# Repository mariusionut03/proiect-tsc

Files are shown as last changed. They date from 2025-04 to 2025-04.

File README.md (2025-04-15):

# OpenBook e-book reader

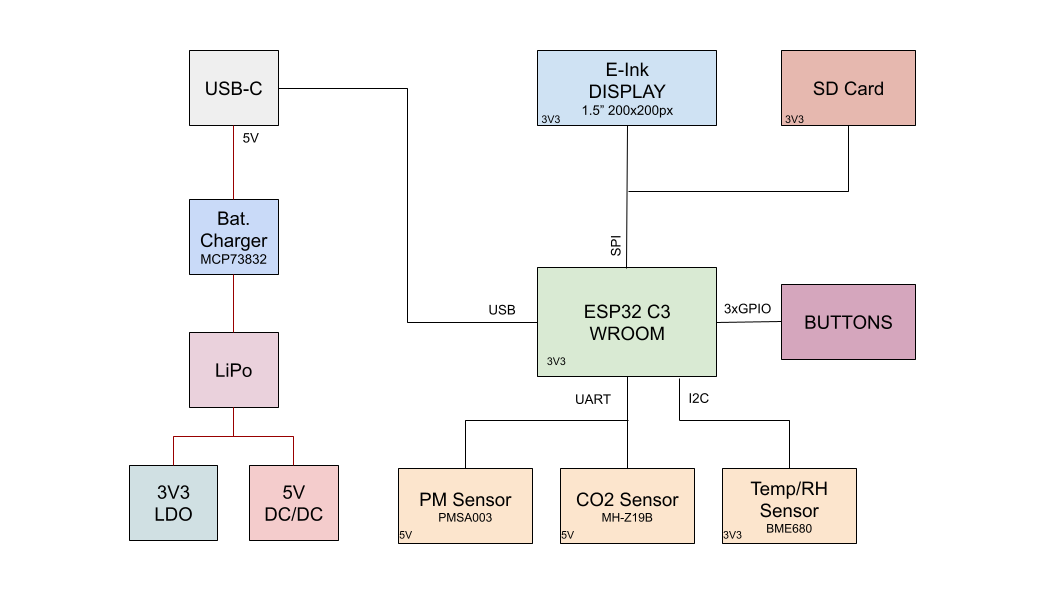
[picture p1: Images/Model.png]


## BOM - Bill of Materials

| Device Module | Amount | Datasheet | Shop |
| --- | --- | ---| ---|
| 112A-TAAR-R03_ATTEND | 1 | https://www.attend.com.tw/en/product.php?act=view&id=253 | https://www.digikey.com/en/products/detail/attend-technology/112A-TAAR-R03/17633923 |
| BD5229G-TR | 1 | https://www.digikey.ph/en/products/detail/rohm-semiconductor/BD5229G-TR/658502 | https://www.digikey.ph/en/products/detail/rohm-semiconductor/BD5229G-TR/658502 |
| BUTTON_COSYOMV1 | 3 | https://components101.com/switches/push-button | https://uk.farnell.com/wurth-elektronik/430182043816/switch-160gf-6x6mm-smd-4-3mm-act/dp/2065105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 |
| CPH3225A | 1 | https://www.digikey.com/en/products/detail/seiko-instruments/CPH3225A/8692444 | https://www.digikey.com/en/products/detail/seiko-instruments/CPH3225A/8692444 |
| DS3231SN | 1 | https://www.digikey.com/en/products/detail/analog-devices-inc-maxim-integrated/DS3231SN/1197576 | https://www.digikey.com/en/products/detail/analog-devices-inc-maxim-integrated/DS3231SN/1197576 |
| BME680 | 1 | https://www.sparkfun.com/sparkfun-environmental-sensor-breakout-bme680-qwiic.html | https://www.sparkfun.com/sparkfun-environmental-sensor-breakout-bme680-qwiic.html |
| MCP73831 | 1 | https://www.microchip.com/en-us/product/mcp73831 | https://www.microchipdirect.com/product/MCP73831T-2ADI/OT |
| C6-WROOM-1-N8 | 1 | https://www.espressif.com/sites/default/files/documentation/esp32-c6-wroom-1_wroom-1u_datasheet_en.pdf | https://www.adafruit.com/product/5671 |
| FH34SRJ-24S-0.5SH_99_ | 1 | https://www.hirose.com/product/p/CL0580-1255-6-99 | https://www.hirose.com/product/p/CL0580-1255-6-99 |
| MAX17048G+T10 | 1 | https://eu.mouser.com/ProductDetail/Analog-Devices-Maxim-Integrated/MAX17048G+T10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 | https://eu.mouser.com/ProductDetail/Analog-Devices-Maxim-Integrated/MAX17048G+T10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 |
| MBR0530 | 3 | https://www.digikey.com/en/products/detail/onsemi/MBR0530/1048783 | https://www.digikey.com/en/products/detail/onsemi/MBR0530/1048783 |
| PGB1010603MR | 6 | https://www.digikey.com/en/products/detail/littelfuse-inc/PGB1010603MR/715755 | https://www.digikey.com/en/products/detail/littelfuse-inc/PGB1010603MR/715755 |
| SAMACSYS_PARTS_USB4110-GF-A | 1 | https://www.digikey.ro/en/products/detail/gct/USB4110-GF-A/10384547 | https://www.digikey.ro/en/products/detail/gct/USB4110-GF-A/10384547 |
| SI1308EDL-T1-GE3 | 1 | https://www.digikey.com/en/products/detail/vishay-siliconix/SI1308EDL-T1-GE3/4876435 | https://www.digikey.com/en/products/detail/vishay-siliconix/SI1308EDL-T1-GE3/4876435 |
| SJ | 1 | https://www.digikey.com/en/products/detail/cui-devices/SJ1-3514N/738685 | https://www.digikey.com/en/products/detail/cui-devices/SJ1-3514N/738685 |
| USBLC6-2SC6Y | 1 | https://www.digikey.com/en/products/detail/stmicroelectronics/USBLC6-2SC6Y/2819177 | https://www.digikey.com/en/products/detail/stmicroelectronics/USBLC6-2SC6Y/2819177 |
| W25Q512JVEIQ | 1 | https://www.digikey.com/en/products/detail/winbond-electronics/W25Q512JVEIQ/10244706 | https://www.digikey.com/en/products/detail/winbond-electronics/W25Q512JVEIQ/10244706 |
| XC6220A331MR-G | 1 | https://www.digikey.com/en/products/detail/torex-semiconductor-ltd/XC6220B331MR-G/2138177 | https://www.digikey.com/en/products/detail/torex-semiconductor-ltd/XC6220B331MR-G/2138177 |
| SD0805S020S1R0 | 2 | https://www.digikey.com/en/products/detail/kyocera-avx/SD0805S020S1R0/3749517 | https://www.digikey.com/en/products/detail/kyocera-avx/SD0805S020S1R0/3749517 |
| LTSPICE_C 100nF | 8 | https://www.digikey.com/en/products/detail/nextgen-components/0402B104K500HI/22601924 | https://www.digikey.com/en/products/detail/nextgen-components/0402B104K500HI/22601924 |
| LTSPICE_C 10nF | 1 | https://www.amazon.com/ALLECIN-Electrolytic-Capacitor-0-2x0-43in-Capacitors/dp/B0CMQC587X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 | https://www.amazon.com/ALLECIN-Electrolytic-Capacitor-0-2x0-43in-Capacitors/dp/B0CMQC587X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 |
| LTSPICE_C 4.7uF | 6 | https://www.amazon.com/ALLECIN-Electrolytic-Capacitor-0-2x0-43in-Capacitors/dp/B0CMQC587X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 | https://www.amazon.com/ALLECIN-Electrolytic-Capacitor-0-2x0-43in-Capacitors/dp/B0CMQC587X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 |
| LTSPICE_C 1uF | 10 | https://www.amazon.com/ALLECIN-Electrolytic-Capacitor-0-2x0-43in-Capacitors/dp/B0CMQC587X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 | https://www.amazon.com/ALLECIN-Electrolytic-Capacitor-0-2x0-43in-Capacitors/dp/B0CMQC587X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 |
| LTSPICE_C 0.1uF | 1 | https://www.digikey.com/en/products/detail/samsung-electro-mechanics/CL10E104KC8VPNC/20498486 | https://www.digikey.com/en/products/detail/samsung-electro-mechanics/CL10E104KC8VPNC/20498486 |
| ADAFRUIT_LED | 1 | https://www.adafruit.com/product/4684 | https://www.adafruit.com/product/4684 |
| ESP32_VARISTOR | 1 | https://uk.rs-online.com/web/p/varistors/9012743 | https://uk.rs-online.com/web/p/varistors/9012743 |
| CT3528 (RCL_CPOL-EU) 100uF | 1 | https://www.datasheetarchive.com/?q=ct3528 |  |
| DMG2305UX-7 20V/4.2A/52mO/1.4W | 2 | https://www.digikey.com/en/products/detail/diodes-incorporated/DMG2305UX-7/4340667 | https://www.digikey.com/en/products/detail/diodes-incorporated/DMG2305UX-7/4340667 |
| IND-4828-WE-TPC-WRE | 1 | https://www.axel-gl.com/en/asone/d/64-0172-48/ | https://www.axel-gl.com/en/asone/d/64-0172-48/ |
| JS-1MM(QWIIC_CONNECTOR) | 1 | https://www.sparkfun.com/qwiic-jst-connector-smd-4-pin-horizontal.html | https://www.sparkfun.com/qwiic-jst-connector-smd-4-pin-horizontal.html |
| LTSPICE_R 5k1 | 2 |  | https://www.amazon.com/BOJACK-Values-Resistor-Resistors-Assortment/dp/B08FD1XVL6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 |
| LTSPICE_R 100k | 1 |  | https://www.amazon.com/BOJACK-Values-Resistor-Resistors-Assortment/dp/B08FD1XVL6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 |
| LTSPICE_R 2.2 | 1 |  | https://www.amazon.com/BOJACK-Values-Resistor-Resistors-Assortment/dp/B08FD1XVL6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 |
| LTSPICE_R 10k | 16 |  | https://www.amazon.com/BOJACK-Values-Resistor-Resistors-Assortment/dp/B08FD1XVL6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 |
| LTSPICE_R 0.47 | 1 |  | https://www.amazon.com/BOJACK-Values-Resistor-Resistors-Assortment/dp/B08FD1XVL6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 |
| LTSPICE_R 2k | 1 |  | https://www.amazon.com/BOJACK-Values-Resistor-Resistors-Assortment/dp/B08FD1XVL6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 |
| LTSPICE_R 200 | 1 |  | https://www.amazon.com/BOJACK-Values-Resistor-Resistors-Assortment/dp/B08FD1XVL6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 |
| LTSPICE_R 15 | 1 |  | https://www.amazon.com/BOJACK-Values-Resistor-Resistors-Assortment/dp/B08FD1XVL6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 |
| Test Pad TP20R | 17 | https://us.misumi-ec.com/vona2/detail/221005496391/?HissuCode=TP20R-24 | https://us.misumi-ec.com/vona2/detail/221005496391/?HissuCode=TP20R-24 |

## ESP32-C6

- EN - RESET (Activare sau dezactivare device)
- IO0 - INT_RTC (Pin pentru intrerupere ale ceasului RTC sau Real Time Clock)
- IO1 - 32KHZ (Ofera o frecventa de 32 kHz, utilizata pentru sincronizare.)
- IO2 - MISO (Master In Slave Out, comunicare SPI pentru primire date de la periferice)
- IO3 - EPD_BUSY (Indica starea ecranului: ocupat sau liber)
- IO4 - SS_SD (Activeaza cardul SD, Slave Select)
- IO5 - EPD_DC (Control pentru date si comenzi ecran)
- IO6 - SCK (Serial Clock)
- IO7 - MOSI (Master Out Slave In, comunicare SPI pentru trimitere date la periferice)
- IO8 - GPIO8
- IO9 - IO/BOOT (Schimbare state dispozitiv)
- IO10 - EPD_CS (Select display)
- IO11 - FLASH_CS (Select memoria Flash)
- IO12 - USB_D- (comunicare USB)
- IO13 - USB_D+ (comunicare USB)
- IO15 - IO/CHANGE (navigare)
- IO16 - TX (Transmitere date)
- IO17 - RX (Receptie date)
- IO18 - RTC_RST (Reset RTC)
- IO19 - I2C_PW (Linia de alimentare pentru periferice I2C)
- IO20 - EPD_3V3_C (Alimentare)
- IO21 - SDA (I2C Data)
- IO22 - SCL (I2C Clock)
- IO23 - EPD_RST (Reset display)
- GND - Connected to ground 

## Randari

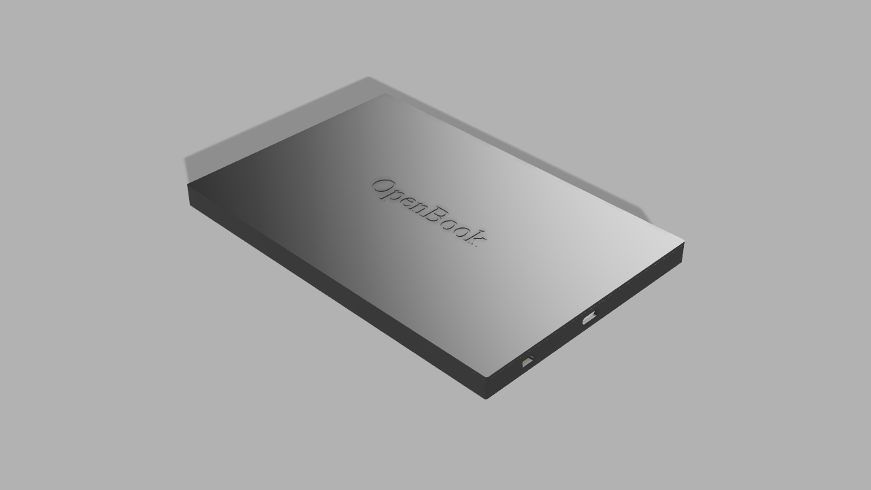
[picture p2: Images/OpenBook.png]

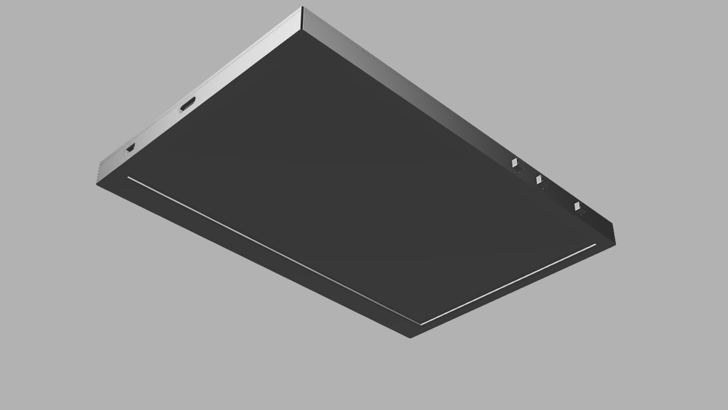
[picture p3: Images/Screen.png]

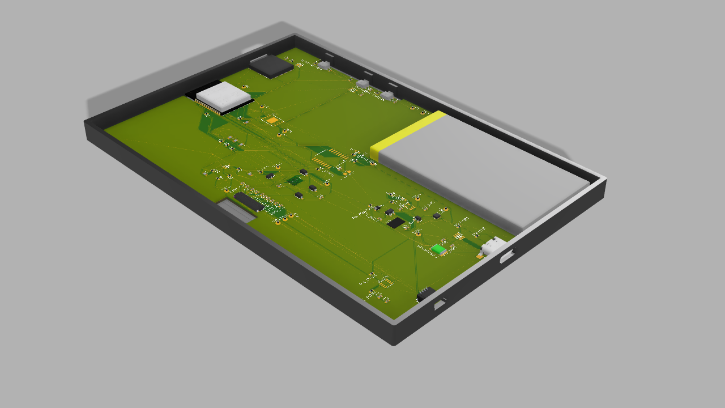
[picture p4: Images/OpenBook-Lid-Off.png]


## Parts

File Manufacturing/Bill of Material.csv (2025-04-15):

Qty | Value | Device | Package | Parts | Description | ARROW_PART_NUMBER | ARROW_PRICE-STOCK | AVAILABILITY | BOOT_BUTTON | CENTROID_NOT_SPECIFIED | CHANGE_BUTTON | CHECK_PRICES | COPYRIGHT | DATASHEET | DESCRIPTION | DIGIKEY_DESCRIPTION | DIGIKEY_PART_NUMBER | HEIGHT | LEAD_FREE | MANUFACTURER_NAME | MANUFACTURER_PART_NUMBER | MF | MFR_NAME | MOUSER_PART_NUMBER | MOUSER_PRICE-STOCK | MOUSER_TESTING_PART_NUMBER | MOUSER_TESTING_PRICE-STOCK | MP | MPN | PACKAGE | POPULARITY | PREFIX | PRICE | PROD_ID | PURCHASE-URL | RESET_BUTTON | ROHS | SNAPEDA_LINK | SPICEPREFIX | TEMPERATURE_RANGE_HIGH | TEMPERATURE_RANGE_LOW | VALUE
1 |  | ADAFRUIT_LEDCHIP-LED0603 | ADAFRUIT_CHIP-LED0603 | CHG_LED | LED
1 |  | SJ | SJ | SJ1 | SMD solder JUMPER |  |  |  |  |  |  |  |  |  |  |  |  |  |  |  |  |  |  |  |  |  |  |  |  |  | 3
1 | 0.1uF/50V | ESP32_WROVER_EAGLE-LTSPICE_C | ESP32_WROVER_EAGLE-LTSPICE_C0402 | EPD_C5 | CAPACITOR, European symbol
1 | 0.47 | ESP32_WROVER_EAGLE-LTSPICE_R | ESP32_WROVER_EAGLE-LTSPICE_R0402 | R3 | RESISTOR, European symbol
1 | 100K | ESP32_WROVER_EAGLE-LTSPICE_R | ESP32_WROVER_EAGLE-LTSPICE_R0402 | R1_PWRUSB | RESISTOR, European symbol
8 | 100nF | ESP32_WROVER_EAGLE-LTSPICE_C | ESP32_WROVER_EAGLE-LTSPICE_C0402 | C1, C2, C4_USB, C6, C8, C9, C10, C_DELAY | CAPACITOR, European symbol
1 | 100uF TANT | RCL_CPOL-EUCT3528 | RCL_CT3528 | C3 | POLARIZED CAPACITOR, European symbol |  |  |  |  |  |  |  |  |  |  |  |  |  |  |  |  |  |  |  |  |  |  |  |  |  | 0 |  |  |  |  |  |  |  | C
16 | 10K | ESP32_WROVER_EAGLE-LTSPICE_R | ESP32_WROVER_EAGLE-LTSPICE_R0402 | R1, R1_PINH, R1_PINH1, R2_PINH, R2_PINH1, R4, R5, R6, R7, R8, R9, R10, R_BOOT, R_CHARGE, R_CL1, R_RESET | RESISTOR, European symbol
1 | 10uF | ESP32_WROVER_EAGLE-LTSPICE_C | ESP32_WROVER_EAGLE-LTSPICE_C0402 | C7 | CAPACITOR, European symbol
1 | 112A-TAAR-R03_ATTEND | 112A-TAAR-R03_ATTEND | 112ATAARR03ATTEND | J4 | Micro SD Card Socket, Push-Push Type, Top Mount, SMT, H=1.83mm, 10u |  |  |  |  |  |  |  |  |  | Micro SD Card Socket | Push-Push Type | Top Mount | SMT | H=1.83mm | 10u |  |  | 1.9mm |  | ATTEND | 112A-TAAR-R03 ATTEND
1 | 15 | ESP32_WROVER_EAGLE-LTSPICE_R | ESP32_WROVER_EAGLE-LTSPICE_R0402 | R_CAPACITOR | RESISTOR, European symbol
1 | 1uF | ESP32_WROVER_EAGLE-LTSPICE_C | ESP32_WROVER_EAGLE-LTSPICE_C0402 | C5 | CAPACITOR, European symbol
9 | 1uF/50V | ESP32_WROVER_EAGLE-LTSPICE_C | ESP32_WROVER_EAGLE-LTSPICE_C0402 | EPD_C1, EPD_C2, EPD_C6, EPD_C7, EPD_C8, EPD_C9, EPD_C10, EPD_C11, EPD_C12 | CAPACITOR, European symbol
1 | 2.2 | ESP32_WROVER_EAGLE-LTSPICE_R | ESP32_WROVER_EAGLE-LTSPICE_R0402 | R2 | RESISTOR, European symbol
1 | 200 | ESP32_WROVER_EAGLE-LTSPICE_R | ESP32_WROVER_EAGLE-LTSPICE_R0402 | R1_BAT | RESISTOR, European symbol
2 | 20V/4.2A/52mO/1.4W | ESP32_WROVER_SPARKFUN-DISCRETESEMI_MOSFET_PCH-DMG2305UX-7 | ESP32_WROVER_SPARKFUN-DISCRETESEMI_SOT23-3 | Q1, Q2 | P-channel MOSFETs |  |  |  |  |  |  |  |  |  |  |  |  |  |  |  |  |  |  |  |  |  |  |  |  |  |  |  |  | TRAN-14388 |  |  |  |  |  |  |  | 20V/4.2A/52mO/1.4W
1 | 2K | ESP32_WROVER_EAGLE-LTSPICE_R | ESP32_WROVER_EAGLE-LTSPICE_R0402 | R2_BAT | RESISTOR, European symbol
5 | 4.7uF | ESP32_WROVER_EAGLE-LTSPICE_C | ESP32_WROVER_EAGLE-LTSPICE_C0402 | C1_BAT, C1_BAT1, C1_BAT2, C2_BAT, C5_USB | CAPACITOR, European symbol
1 | 4.7uF/25V | ESP32_WROVER_EAGLE-LTSPICE_C | ESP32_WROVER_EAGLE-LTSPICE_C0402 | C4 | CAPACITOR, European symbol
2 | 5k1 | ESP32_WROVER_EAGLE-LTSPICE_R | ESP32_WROVER_EAGLE-LTSPICE_R0402 | R2-USB, R2-USB1 | RESISTOR, European symbol
1 | 68uH | 744043680IND_4828-WE-TPC_WRE | IND_4828-WE-TPC_WRE | L1 |  |  |  |  |  |  |  |  | Copyright (C) 2024 Ultra Librarian. All rights reserved. |  |  |  |  |  |  |  | 744043680 |  | Wurth Electronics
1 | BD5229G-TR | BD5229G-TR | SOT95P280X125-5N | IC1 | Voltage Detector with Adjustable Delay Time: CMOS processes are utilized to develop high precision, low current consumption CMOS reset ICs that allow arbitrary setting of the delay time. The extensive lineup includes both Nch Open Drain and CMOS output types in a wide range of detection voltages (from 2.3V to 6.0V, in 0.1V steps), enabling selection of the ideal solution based on customer requirements. In addition, the entire series is of course both lead-free and RoHS-compliant. |  |  |  |  |  |  |  |  |  | Voltage Detector with Adjustable Delay Time: CMOS processes are utilized to develop high precision | low current consumption CMOS reset ICs that allow arbitrary setting of the delay time. The extensive lineup includes both Nch Open Drain and CMOS output types in a wide range of detection voltages (from 2.3V to 6.0V | in 0.1V steps) | enabling selection of the ideal solution based on customer requirements. In addition | the entire series is of course both lead-free and RoHS-compliant. |  |  | 1.25mm |  | ROHM Semiconductor | BD5229G-TR |  |  | 755-BD5229G-TR | https://www.mouser.co.uk/ProductDetail/ROHM-Semiconductor/BD5229G-TR?qs=4kLU8WoGk0vvnhrrYwdszw%3D%3D
3 | BUTTON_CUSYOMV1BUTTONMODEL | BUTTON_CUSYOMV1BUTTONMODEL | MYBUTTON | CHANGE_BUTTON, RESET_BUTTON, U$2
1 | CPH3225A | CPH3225A | CAPCP3225X100N | C10_SUPERCAP | Cap 0.011F 3.3V 1210 Flat Check availability |  |  | Not in stock |  |  |  | https://www.snapeda.com/parts/CPH3225A/Seiko+Instruments/view-part/?ref=eda |  |  | 11 mF (EDLC) Supercapacitor 3.3 V 1210 (3225 Metric) - - |  |  |  |  |  |  | Seiko Instruments |  |  |  |  |  | CPH3225A |  | 1210 Seiko |  |  | None |  | https://www.snapeda.com/api/url_track_click_mouser/?unipart_id=562593&manufacturer=Seiko Instruments&part_name=CPH3225A&search_term=None |  |  | https://www.snapeda.com/parts/CPH3225A/Seiko+Instruments/view-part/?ref=snap
1 | DS3231SN# | DS3231SN# | SOIC127P1032X265-16N | U3 | Real Time Clock Serial 16-Pin SOIC W T/R Check availability |  |  | In Stock |  |  |  | https://www.snapeda.com/parts/DS3231SN%23/Analog+Devices/view-part/?ref=eda |  |  | Extremely Accurate I²C-Integrated RTC/TCXO/Crystal |  |  |  |  |  |  | Analog Devices |  |  |  |  |  | DS3231SN# |  | SOIC-16 Maxim |  |  | None |  | https://www.snapeda.com/api/url_track_click_mouser/?unipart_id=99048&manufacturer=Analog Devices&part_name=DS3231SN#&search_term=None |  |  | https://www.snapeda.com/parts/DS3231SN%23/Analog+Devices/view-part/?ref=snap
1 | ESP32-C6-WROOM-1-N8 | ESP32-C6-WROOM-1-N8 | XCVR_ESP32-C6-WROOM-1-N8 | U2 | Check availability |  |  | In Stock |  |  |  | https://www.snapeda.com/parts/ESP32-C6-WROOM-1-N8/Espressif+Systems/view-part/?ref=eda |  |  | Multiprotocol Modules ESP32-C6 module | Wi-Fi 6 in 2.4 GHz band | Bluetooth 5 | Zigbee 3.0 and Thread. ESP34-WROOM Compatible - ENGINEERING SAMPLE |  |  |  |  |  |  | Espressif Systems |  |  |  |  |  | ESP32-C6-WROOM-1-N8 |  | None |  |  | None |  |  |  |  | https://www.snapeda.com/parts/ESP32-C6-WROOM-1-N8/Espressif+Systems/view-part/?ref=snap
1 | ESP32C6_VARISTORCN1812 | ESP32C6_VARISTORCN1812 | ESP32C6_VARISTOR_CT/CN1812 | PFMF.050.1 | VARISTOR |  |  |  |  |  |  |  |  |  |  |  |  |  |  |  |  |  |  |  |  |  |  |  |  |  | 0
2 | ESP32_WROVER_AVX---SD0805S020S1R0_AVX_SD0805S020S1R0_0_0AVX_SD0805S020S1R0_0_0 | ESP32_WROVER_AVX---SD0805S020S1R0_AVX_SD0805S020S1R0_0_0AVX_SD0805S020S1R0_0_0 | ESP32_WROVER_AVX---SD0805S020S1R0_AVX_SD0805S020S1R0_0 | D2, D7 | Schottky Barrier Rectifier Diode |  |  |  |  | No |  |  |  | http://datasheets.avx.com/schottky.pdf |  | DIODE SCHOTTKY 20V 1A 0805 | 478-7800-1-ND |  | yes |  |  | AVX |  | 581-SD0805S020S1R0 |  |  |  |  |  | 0805 (2012 metric) |  | D |  |  |  |  | yes |  |  | +125°C | -55°C
1 | ESP32_WROVER_BME680_BME680 | ESP32_WROVER_BME680_BME680 | ESP32_WROVER_BME680_PSON80P300X300X100-8N | SENSOR2 | Integrated Environmental Unit |  |  | Unavailable |  |  |  |  |  |  | Integrated Environmental Unit |  |  |  |  |  |  | Bosch Sensortec |  |  |  |  |  | BME680 |  | LGA-8 Bosch Tools |  |  | None
1 | ESP32_WROVER_SPARKFUN-IC-POWER_MCP73831 | ESP32_WROVER_SPARKFUN-IC-POWER_MCP73831 | ESP32_WROVER_SPARKFUN-IC-POWER_SOT23-5 | MCP73831 | MCP73831T Li-Ion, Li-Pol Controller |  |  |  |  |  |  |  |  |  |  |  |  |  |  |  |  |  |  |  |  |  |  |  |  |  |  |  |  | IC-09995
1 | FH34SRJ-24S-0.5SH_99_ | FH34SRJ-24S-0.5SH_99_ | FH34SRJ24S05SH99 | J1 | (0.50mm) Surface Mount, Right Angle |  |  |  |  |  |  |  |  |  | 24 Position FFC | FPC Connector Contacts | (0.50mm) Surface Mount | Right Angle |  |  | 1.1mm |  | Hirose | FH34SRJ-24S-0.5SH(99) |  |  | 798-FH34SRJ24S05SH99 | https://www.mouser.co.uk/ProductDetail/Hirose-Connector/FH34SRJ-24S-0.5SH99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
1 | MAX17048G+T10 | MAX17048G+T10 | SON50P200X200X80-9N | U4 | Check availability |  |  | In Stock |  |  |  | https://www.snapeda.com/parts/MAX17048G+T10/Analog+Devices/view-part/?ref=eda |  |  | 3µA 1-Cell/2-Cell Fuel Gauge with ModelGauge |  |  |  |  |  |  | Analog Devices |  |  |  |  |  | MAX17048G+T10 |  | TDFN-8 Maxim |  |  | None |  | https://www.snapeda.com/api/url_track_click_mouser/?unipart_id=329239&manufacturer=Analog Devices&part_name=MAX17048G+T10&search_term=None |  |  | https://www.snapeda.com/parts/MAX17048G+T10/Analog+Devices/view-part/?ref=snap
3 | MBR0530COSTUM | MBR0530COSTUM | SOD3716X135N | D3, D4, D5 | ON SEMICONDUCTOR - MBR0530 - DIODE, SCHOTTKY, 0.5A, 30V, SOD-123
6 | PGB1010603MRCOSTUM | PGB1010603MRCOSTUM | DIOC1608X36N | D6, D8, D9, D10, D11, D12 | Check availability
1 | QWIIC_RIGHT_ANGLE | QWIIC_CONNECTORJS-1MM | JST04_1MM_RA | J3 | SparkFun I2C Standard Qwiic Connector |  |  |  |  |  |  |  |  |  |  |  |  |  |  |  |  |  |  |  |  |  |  |  |  |  |  |  |  | CONN-13694 |  |  |  |  |  |  |  | QWIIC_RIGHT_ANGLE
1 | SAMACSYS_PARTS_USB4110-GF-A | SAMACSYS_PARTS_USB4110-GF-A | SAMACSYS_PARTS_USB4110GFA | J2 | CONN USB 2.0 TYPE-C R/A SMT |  |  |  |  |  |  |  |  |  | CONN USB 2.0 TYPE-C R/A SMT |  |  | 3.26mm |  | GCT (GLOBAL CONNECTOR TECHNOLOGY) | USB4110-GF-A |  |  | 640-USB4110-GF-A | https://www.mouser.co.uk/ProductDetail/GCT/USB4110-GF-A?qs=KUoIvG%2F9IlYiZvIXQjyJeA%3D%3D
1 | SI1308EDL-T1-GE3 | SI1308EDL-T1-GE3 | SOT65P210X110-3N | Q3 | MOSFET N-Ch 30V 1.5A TrenchFET SC70 Vishay Si1308EDL-T1-GE3 N-channel MOSFET Transistor, 1.5 A, 30 V, 3-Pin SC-70 |  |  | In Stock |  |  |  | https://www.snapeda.com/parts/SI1308EDL-T1-GE3/Vishay+Siliconix/view-part/?ref=eda |  |  | Si1308EDL-T1-GE3 N-channel MOSFET Transistor | 1.5 A | 30 V | 3-Pin SC-70 | Siliconix / Vishay SI1308EDL-T1-GE3 |  |  |  |  |  |  | Vishay Siliconix |  |  |  |  |  | SI1308EDL-T1-GE3 |  | SOT-323 Vishay Semiconductor |  |  | None |  | https://www.snapeda.com/api/url_track_click_mouser/?unipart_id=274603&manufacturer=Vishay Siliconix&part_name=SI1308EDL-T1-GE3&search_term=None |  |  | https://www.snapeda.com/parts/SI1308EDL-T1-GE3/Vishay+Siliconix/view-part/?ref=snap
17 | TP | TP | TP20R | TP1, TP2, TP3, TP4, TP5, TP6, TP7, TP8, TP9, TP10, TP11, TP12, TP13, TP14, TP15, TP16, TP17 | Test pad
1 | USBLC6-2SC6Y | USBLC6-2SC6Y | SOT95P280X145-6N | D1 | Low Cap. ESD Protection Auto SOT-23-6 STMicroelectronics USBLC6-2SC6Y, Dual Uni-Directional TVS Diode Array, 6-Pin SOT-23 |  |  | In Stock |  |  |  | https://www.snapeda.com/parts/USBLC6-2SC6Y/STMicroelectronics/view-part/?ref=eda |  |  | 17V Clamp 5A (8/20µs) Ipp Tvs Diode Surface Mount SOT-23-6 |  |  |  |  |  |  | STMicroelectronics |  |  |  |  |  | USBLC6-2SC6Y |  | SOT-23-6 STMicroelectronics |  |  | None |  |  |  |  | https://www.snapeda.com/parts/USBLC6-2SC6Y/STMicroelectronics/view-part/?ref=snap
1 | W25Q512JVEIQ | W25Q512JVEIQ | SON127P600X800X80-9N | U1 | Check availability |  |  | In Stock |  |  |  | https://www.snapeda.com/parts/W25Q512JVEIQ/Winbond+Electronics/view-part/?ref=eda |  |  | FLASH - NOR Memory IC 512Mb (64M x 8) SPI - Quad I/O 133 MHz 8-WSON (8x6) |  |  |  |  |  |  | Winbond Electronics |  |  |  |  |  | W25Q512JVEIQ |  | Package |  |  | None |  |  |  |  | https://www.snapeda.com/parts/W25Q512JVEIQ/Winbond+Electronics/view-part/?ref=snap
1 | XC6220A331MR-G | XC6220A331MR-G | SOT95P280X120-5N | IC4 | LDO Voltage Regulators |  |  |  |  |  |  |  |  |  | LDO Voltage Regulators |  |  | 1.2mm |  | Torex | XC6220A331MR-G |  |  | 865-XC6220A331MR-G | https://www.mouser.co.uk/ProductDetail/Torex-Semiconductor/XC6220A331MR-G?qs=AsjdqWjXhJ8ZSWznL1J0gg%3D%3D

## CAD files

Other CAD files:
Mechanical/OpenBook.f3z

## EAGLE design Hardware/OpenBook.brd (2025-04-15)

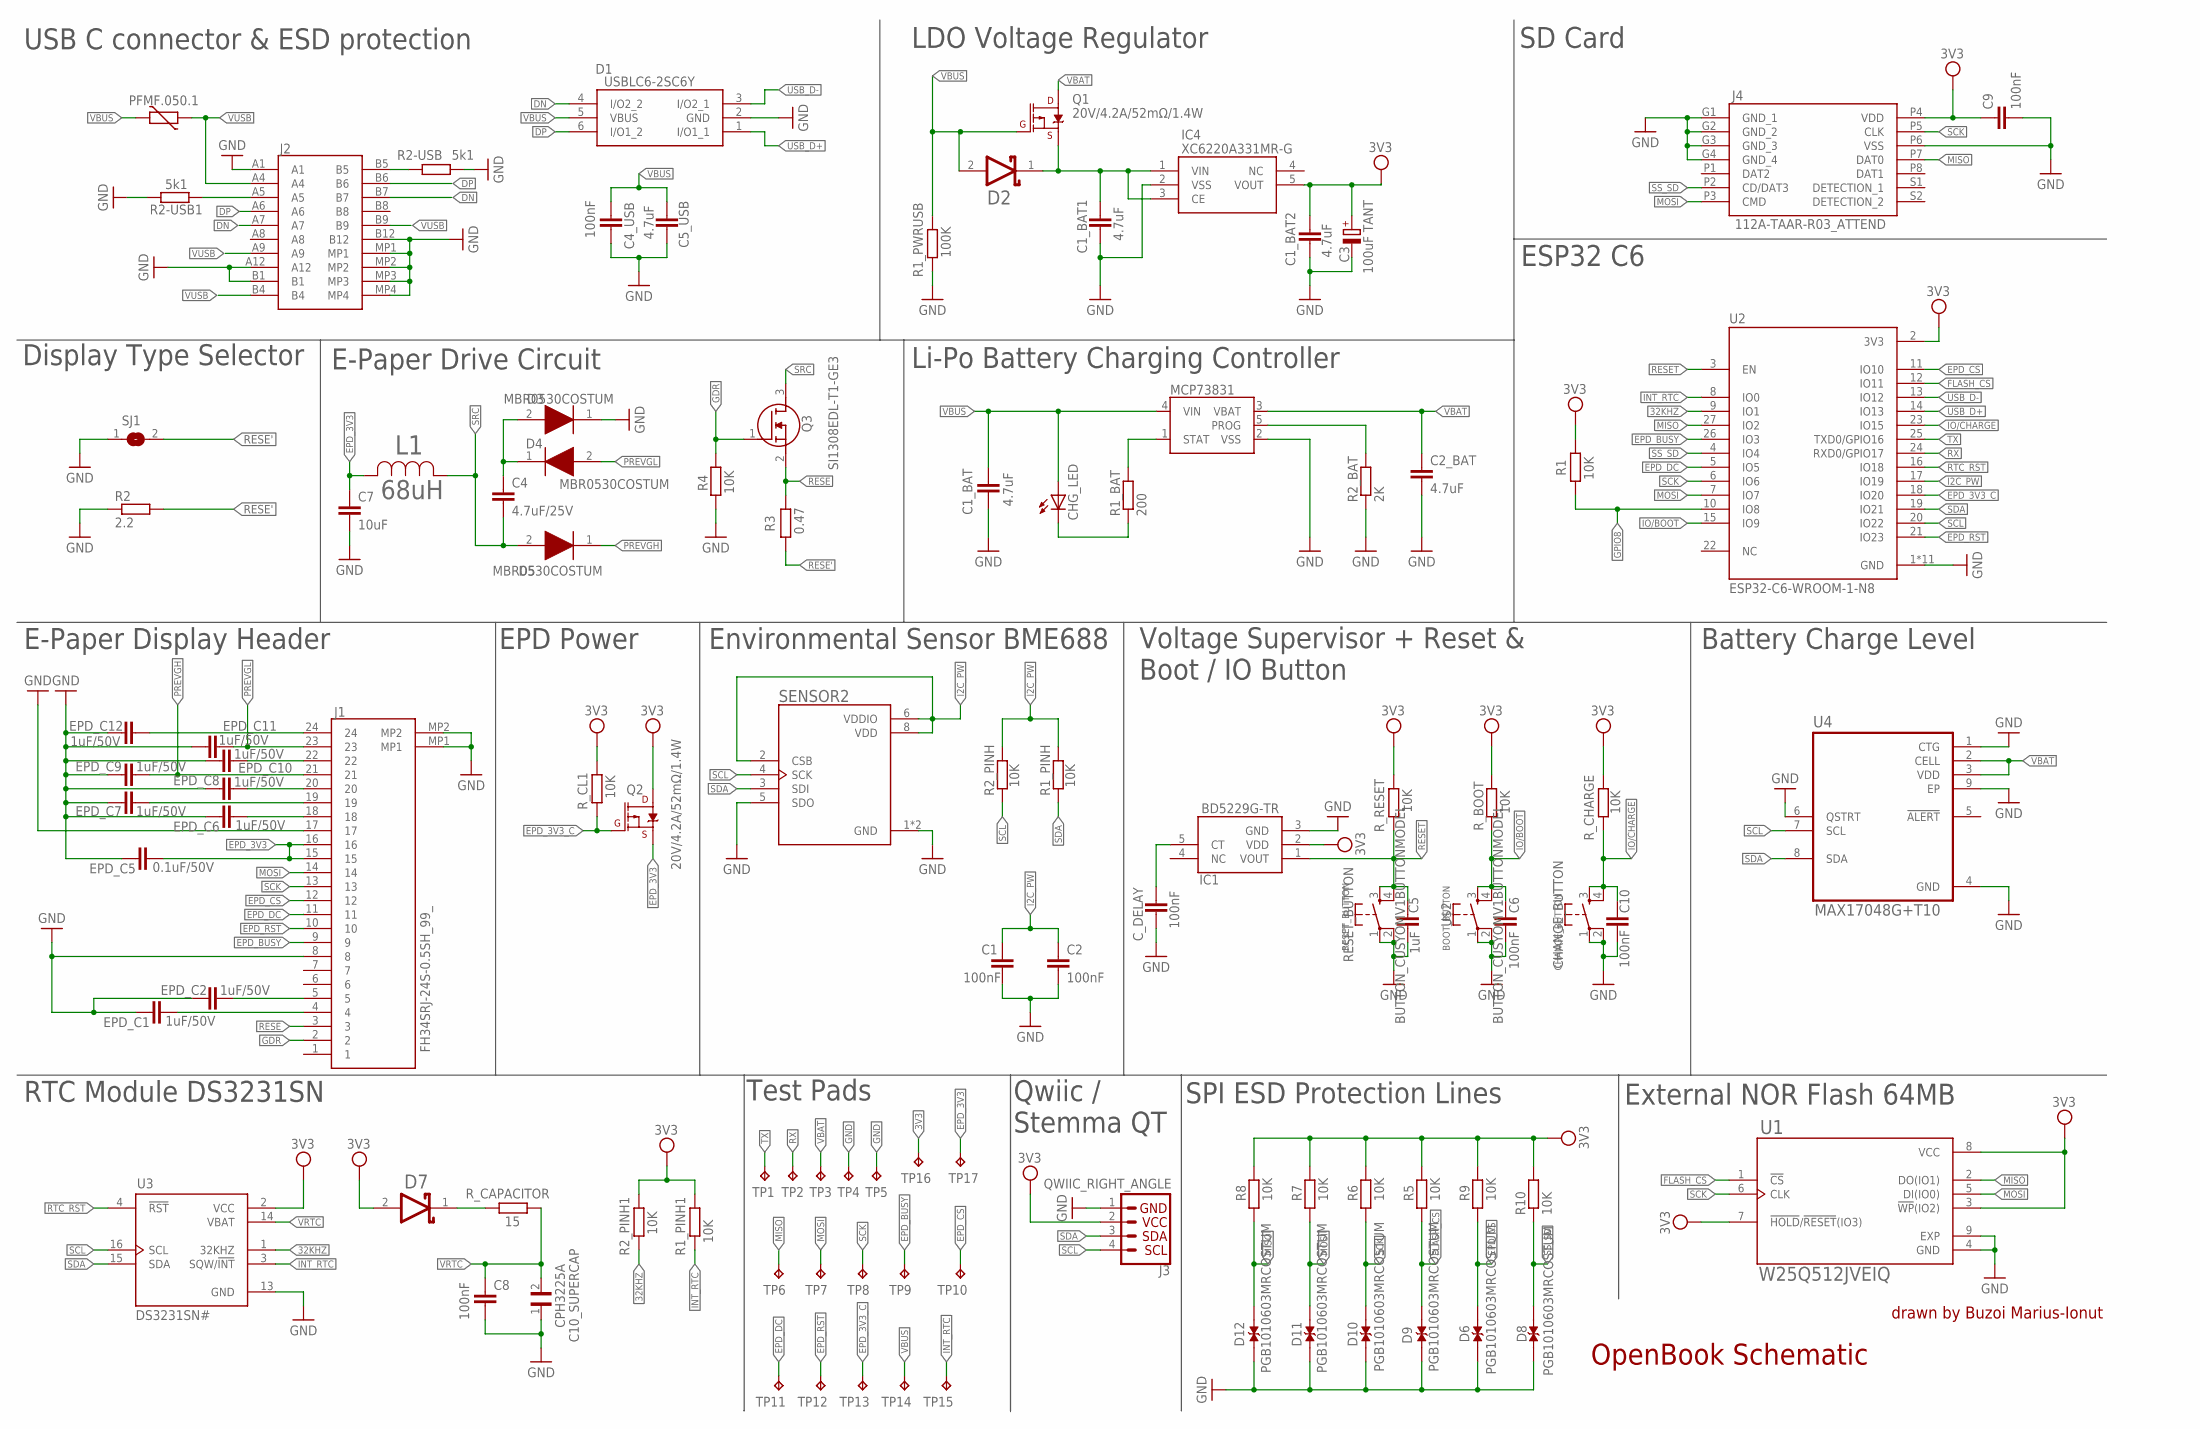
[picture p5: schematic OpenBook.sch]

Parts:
C1, C2, C4_USB, C6, C8, C9, C10: 100nF; ESP32_WROVER_EAGLE-LTSPICE_C0402
C1_BAT, C1_BAT1, C1_BAT2, C2_BAT, C5_USB: 4.7uF; ESP32_WROVER_EAGLE-LTSPICE_C0402
C3: 100uF TANT; RCL_CT3528
C4: 4.7uF/25V; ESP32_WROVER_EAGLE-LTSPICE_C0402
C5: 1uF; ESP32_WROVER_EAGLE-LTSPICE_C0402
C7: 10uF; ESP32_WROVER_EAGLE-LTSPICE_C0402
C10_SUPERCAP: CPH3225A; CAPCP3225X100N
CHANGE_BUTTON: BUTTON_CUSYOMV1BUTTONMODEL; MYBUTTON
CHG_LED: ADAFRUIT_LEDCHIP-LED0603; ADAFRUIT_CHIP-LED0603
C_DELAY: 100nF; ESP32_WROVER_EAGLE-LTSPICE_C0402
D1: USBLC6-2SC6Y; SOT95P280X145-6N
D2, D7: ESP32_WROVER_AVX---SD0805S020S1R0_AVX_SD0805S020S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; ESP32_WROVER_AVX---SD0805S020S1R0_AVX_SD0805S020S1R0_0
D3, D4, D5: MBR0530COSTUM; SOD3716X135N
D6, D8, D9, D10, D11, D12: PGB1010603MRCOSTUM; DIOC1608X36N
EPD_C1, EPD_C2, EPD_C6, EPD_C7, EPD_C8, EPD_C9, EPD_C10, EPD_C11, EPD_C12: 1uF/50V; ESP32_WROVER_EAGLE-LTSPICE_C0402
EPD_C5: 0.1uF/50V; ESP32_WROVER_EAGLE-LTSPICE_C0402
IC1: BD5229G-TR; SOT95P280X125-5N
IC4: XC6220A331MR-G; SOT95P280X120-5N
J1: FH34SRJ-24S-0.5SH_99_; FH34SRJ24S05SH99
J2: SAMACSYS_PARTS_USB4110-GF-A; SAMACSYS_PARTS_USB4110GFA
J3: QWIIC_RIGHT_ANGLE; JST04_1MM_RA
J4: 112A-TAAR-R03_ATTEND; 112ATAARR03ATTEND
L1: 68uH; IND_4828-WE-TPC_WRE
MCP73831: ESP32_WROVER_SPARKFUN-IC-POWER_MCP73831; ESP32_WROVER_SPARKFUN-IC-POWER_SOT23-5
PFMF.050.1: ESP32C6_VARISTORCN1812; ESP32C6_VARISTOR_CT/CN1812
Q1, Q2: 20V/4.2A/52mΩ/1.4W; ESP32_WROVER_SPARKFUN-DISCRETESEMI_SOT23-3
Q3: SI1308EDL-T1-GE3; SOT65P210X110-3N
R1, R1_PINH, R1_PINH1, R2_PINH, R2_PINH1, R4, R5, R6, R7, R8, R9, R10: 10K; ESP32_WROVER_EAGLE-LTSPICE_R0402
R1_BAT: 200; ESP32_WROVER_EAGLE-LTSPICE_R0402
R1_PWRUSB: 100K; ESP32_WROVER_EAGLE-LTSPICE_R0402
R2: 2.2; ESP32_WROVER_EAGLE-LTSPICE_R0402
R2-USB, R2-USB1: 5k1; ESP32_WROVER_EAGLE-LTSPICE_R0402
R2_BAT: 2K; ESP32_WROVER_EAGLE-LTSPICE_R0402
R3: 0.47; ESP32_WROVER_EAGLE-LTSPICE_R0402
RESET_BUTTON: BUTTON_CUSYOMV1BUTTONMODEL; MYBUTTON
R_BOOT: 10K; ESP32_WROVER_EAGLE-LTSPICE_R0402
R_CAPACITOR: 15; ESP32_WROVER_EAGLE-LTSPICE_R0402
R_CHARGE: 10K; ESP32_WROVER_EAGLE-LTSPICE_R0402
R_CL1: 10K; ESP32_WROVER_EAGLE-LTSPICE_R0402
R_RESET: 10K; ESP32_WROVER_EAGLE-LTSPICE_R0402
SENSOR2: ESP32_WROVER_BME680_BME680; ESP32_WROVER_BME680_PSON80P300X300X100-8N
SJ1: SJ
TP1, TP2, TP3, TP4, TP5, TP6, TP7, TP8, TP9, TP10, TP11, TP12, TP13, TP14, TP15, TP16, TP17: TP; TP20R
U1: W25Q512JVEIQ; SON127P600X800X80-9N
U2: ESP32-C6-WROOM-1-N8; XCVR_ESP32-C6-WROOM-1-N8
U3: DS3231SN#; SOIC127P1032X265-16N
U4: MAX17048G+T10; SON50P200X200X80-9N
U$2: BUTTON_CUSYOMV1BUTTONMODEL; MYBUTTON

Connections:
3V3: C1_BAT2.1, C3.+, C9.1, D7.2 (ANODE), IC1.2 (VDD), IC4.5 (VOUT), J3.2, J4.P4 (VDD), Q2.3 (D), R1.2, R1_PINH1.2, R2_PINH1.2, R5.2, R6.2, R7.2, R8.2, R9.2, R10.2, R_BOOT.2, R_CHARGE.2, R_CL1.2, R_RESET.2, TP16.TP, U1.3 (!WP!(IO2)), U1.7 (!HOLD!/!RESET!(IO3)), U1.8 (VCC), U2.2 (3V3), U3.2 (VCC)
32KHZ: R2_PINH1.1, U2.9 (IO1), U3.1 (32KHZ)
DN: D1.4 (I/O2_2), J2.A7, J2.B7
DP: D1.6 (I/O1_2), J2.A6, J2.B6
EPD_3V3: C7.1, EPD_C5.2, J1.15, J1.16, L1.2, Q2.2 (S), TP17.TP
EPD_3V3_C: Q2.1 (G), R_CL1.1, TP13.TP, U2.18 (IO20)
EPD_BUSY: J1.9, TP9.TP, U2.26 (IO3)
EPD_CS: D6.2, J1.12, R9.1, TP10.TP, U2.11 (IO10)
EPD_DC: J1.11, TP11.TP, U2.5 (IO5)
EPD_RST: J1.10, TP12.TP, U2.21 (IO23)
FLASH_CS: D9.2, R5.1, U1.1 (!CS), U2.12 (IO11)
GDR: J1.2, Q3.1 (G), R4.2
GND: C1.2, C1_BAT.2, C1_BAT1.2, C1_BAT2.2, C2.2, C2_BAT.2, C3.-, C4_USB.2, C5.2, C5_USB.2, C6.2, C7.2, C8.2, C9.2, C10.2, C10_SUPERCAP.1, CHANGE_BUTTON.1, CHANGE_BUTTON.2, C_DELAY.2, D1.2 (GND), D3.1 (K), D6.1, D8.1, D9.1, D10.1, D11.1, D12.1, EPD_C1.1, EPD_C2.1, EPD_C5.1, EPD_C6.1, EPD_C7.1, EPD_C8.1, EPD_C9.1, EPD_C10.1, EPD_C11.1, EPD_C12.1, IC1.3 (GND), IC4.2 (VSS), J1.8, J1.17, J1.MP1, J1.MP2, J2.A1, J2.A12, J2.B1, J2.B12, J2.MP1, J2.MP2, J2.MP3, J2.MP4, J3.1, J4.G1 (GND_1), J4.G2 (GND_2), J4.G3 (GND_3), J4.G4 (GND_4), J4.P6 (VSS), MCP73831.2 (VSS), R1_PWRUSB.1, R2.1, R2-USB.2, R2-USB1.1, R2_BAT.1, R4.1, RESET_BUTTON.1, RESET_BUTTON.2, SENSOR2.1 (GND), SENSOR2.5 (SDO), SENSOR2.7 (GND), SJ1.1, TP4.TP, TP5.TP, U1.4 (GND), U1.9 (EXP), U2.1 (GND), U2.28 (GND), U2.29_1 (GND), U2.29_2 (GND), U2.29_3 (GND), U2.29_4 (GND), U2.29_5 (GND), U2.29_6 (GND), U2.29_7 (GND), U2.29_8 (GND), U2.29_9 (GND), U3.13 (GND), U4.1 (CTG), U4.4 (GND), U4.6 (QSTRT), U4.9 (EP), U$2.1, U$2.2
GPIO8: R1.1, U2.10 (IO8)
I2C_PW: C1.1, C2.1, R1_PINH.2, R2_PINH.2, SENSOR2.2 (CSB), SENSOR2.6 (VDDIO), SENSOR2.8 (VDD), U2.17 (IO19)
INT_RTC: R1_PINH1.1, TP15.TP, U2.8 (IO0), U3.3 (SQW/!INT)
IO/BOOT: C6.1, R_BOOT.1, U2.15 (IO9), U$2.3, U$2.4
IO/CHARGE: C10.1, CHANGE_BUTTON.3, CHANGE_BUTTON.4, R_CHARGE.1, U2.23 (IO15)
MISO: D12.2, J4.P7 (DAT0), R8.1, TP6.TP, U1.2 (DO(IO1)), U2.27 (IO2)
MOSI: D11.2, J1.14, J4.P3 (CMD), R7.1, TP7.TP, U1.5 (DI(IO0)), U2.7 (IO7)
unnamed: J2.A5, R2-USB1.2
unnamed: C1_BAT1.1, D2.1 (CATHODE), IC4.1 (VIN), IC4.3 (CE), Q1.2 (S)
unnamed: MCP73831.1 (STAT), R1_BAT.2
unnamed: J2.B5, R2-USB.1
unnamed: CHG_LED.C, R1_BAT.1
unnamed: C4.1, D3.2 (A), D4.1 (K)
unnamed: EPD_C12.2, J1.24
unnamed: MCP73831.5 (PROG), R2_BAT.2
unnamed: C_DELAY.1, IC1.5 (CT)
unnamed: EPD_C10.2, J1.22
unnamed: EPD_C8.2, J1.20
unnamed: D7.1 (CATHODE), R_CAPACITOR.1
unnamed: EPD_C7.2, J1.19
unnamed: EPD_C6.2, J1.18
unnamed: EPD_C2.2, J1.5
unnamed: EPD_C1.2, J1.4
PREVGH: D5.1 (K), EPD_C9.2, J1.21
PREVGL: D4.2 (A), EPD_C11.2, J1.23
RESE: J1.3, Q3.2 (S), R3.2
RESE': R2.2, R3.1, SJ1.2
RESET: C5.1, IC1.1 (VOUT), RESET_BUTTON.3, RESET_BUTTON.4, R_RESET.1, U2.3 (EN)
RTC_RST: U2.16 (IO18), U3.4 (!RST)
RX: TP2.TP, U2.24 (RXD0/GPIO17)
SCK: D10.2, J1.13, J4.P5 (CLK), R6.1, TP8.TP, U1.6 (CLK), U2.6 (IO6)
SCL: J3.4, R2_PINH.1, SENSOR2.4 (SCK), U2.20 (IO22), U3.16 (SCL), U4.7 (SCL)
SDA: J3.3, R1_PINH.1, SENSOR2.3 (SDI), U2.19 (IO21), U3.15 (SDA), U4.8 (SDA)
SRC: C4.2, D5.2 (A), L1.1, Q3.3 (D)
SS_SD: D8.2, J4.P2 (CD/DAT3), R10.1, U2.4 (IO4)
TX: TP1.TP, U2.25 (TXD0/GPIO16)
USB_D+: D1.1 (I/O1_1), U2.14 (IO13)
USB_D-: D1.3 (I/O2_1), U2.13 (IO12)
VBAT: C2_BAT.1, MCP73831.3 (VBAT), Q1.3 (D), TP3.TP, U4.2 (CELL), U4.3 (VDD)
VBUS: C1_BAT.1, C4_USB.1, C5_USB.1, CHG_LED.A, D1.5 (VBUS), D2.2 (ANODE), MCP73831.4 (VIN), PFMF.050.1.2, Q1.1 (G), R1_PWRUSB.2, TP14.TP
VRTC: C8.1, C10_SUPERCAP.2, R_CAPACITOR.2, U3.14 (VBAT)
VUSB: J2.A4, J2.A9, J2.B4, J2.B9, PFMF.050.1.1

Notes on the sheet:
drawn by Buzoi Marius-Ionut
OpenBook Schematic
USB C connector & ESD protection
LDO Voltage Regulator
SD Card
Display Type Selector
E-Paper Drive Circuit
Li-Po Battery Charging Controller
ESP32 C6
E-Paper Display Header
EPD Power
Environmental Sensor BME688
Voltage Supervisor + Reset & Boot / IO Button
Battery Charge Level
RTC Module DS3231SN
Test Pads
Qwiic / Stemma QT
SPI ESD Protection Lines
External NOR Flash 64MB

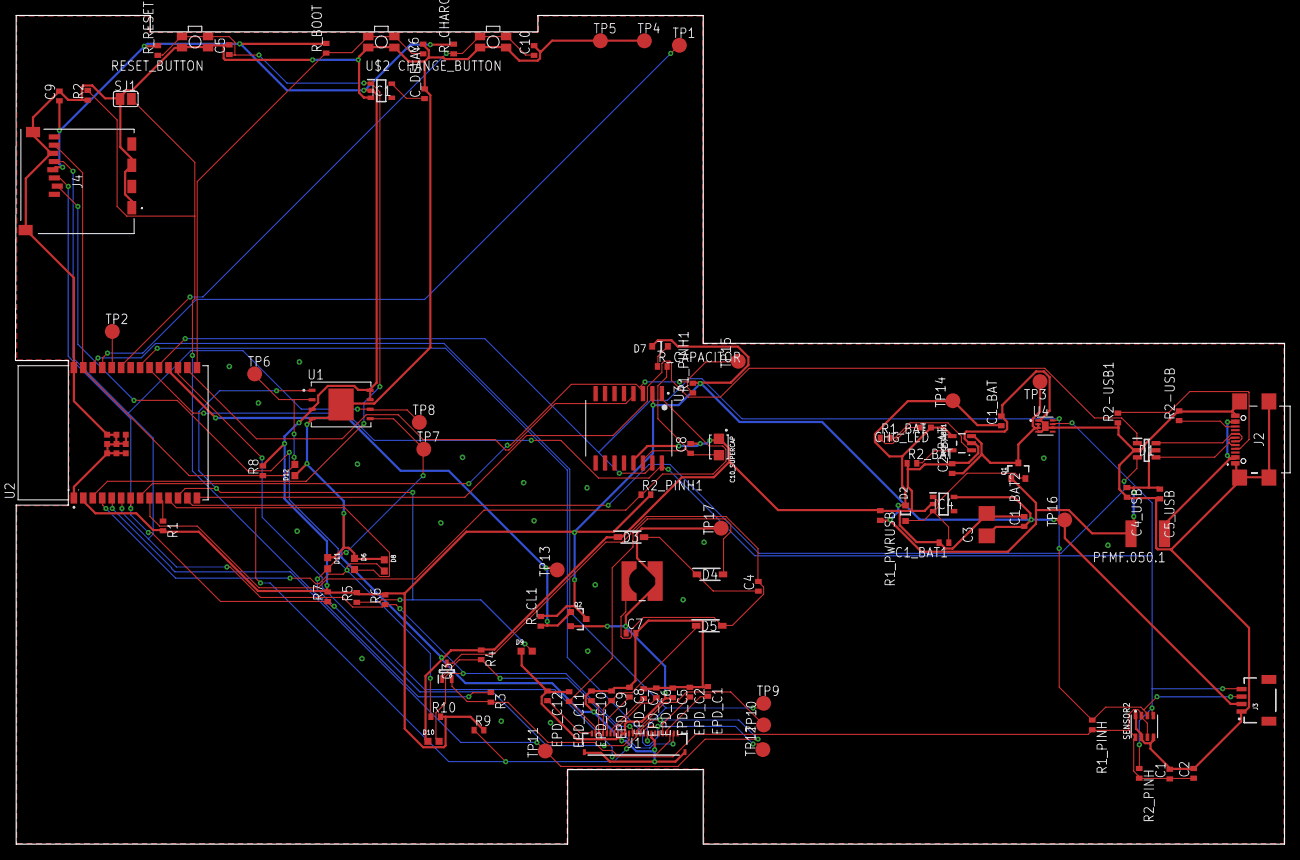
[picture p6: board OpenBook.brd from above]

Board: 2 copper layers, 170.3 x 111.2 mm, 103 parts (0 on the bottom side), 55 nets.

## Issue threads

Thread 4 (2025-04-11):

Issue SMD copper width

mihai1400, 2025-04-11:
Aceasta eroare se poate rezolva prin modificarea Footprint-ului piesei.

mariusionut03, 2025-04-13:
Pad-ul de VBAT de pe componenta este prea mica pentru firul de 0.3 mm. Erorile au fost setate ca "Approved".

Closed 2025-04-13.

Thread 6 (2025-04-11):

De adaugat mai multe poze in ./Images

mihai1400, 2025-04-11:
De adaugat mai multe poze cu fiecare piesa in parte (randarea PCB-ului in 3d, display, baterie)

mariusionut03, 2025-04-15:
Poze de la randare au fost puse in directorul Images din proiect.

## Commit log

2025-03-20 Device Schematic
    [Schematic.sch]
2025-04-02 usbc/esd protection/ldo voltage sch + brd; board shape
    [OpenBook_Board.brd, OpenBook_Schematic.sch, Schematic.sch]
2025-04-06 added project files
    [BOM.csv, OpenBook v14.csv, OpenBook+Enclosure.f3z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]
2025-04-13 Removed older versions; solved wrong components placing in PCB
    [BOM.csv, OpenBook v14.csv, OpenBook+Enclosure.f3z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]
2025-04-15 added 3d models for components; added render images
    [OpenBook.brd, OpenBook.f3z, OpenBook.sch]
2025-04-15 Manufacturing files
    [Bill of Material.csv, Pick and Place.csv]

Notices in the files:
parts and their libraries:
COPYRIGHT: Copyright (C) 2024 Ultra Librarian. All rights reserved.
